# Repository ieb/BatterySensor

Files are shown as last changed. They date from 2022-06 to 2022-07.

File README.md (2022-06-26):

# Battery Sensor

Aim is to create a low power smat shunt batter sensor reporting volage, current and temperatire over ModbusRTU.

Shunt is measured using a MAX9918 shut amplifier amplifying 48x a 75mV/100A shunt scaled down to 50mV to keep the MAX9918 input optimal.
Temperature by a 10K NTC read by ADC using an interpolation table.
Voltage by direct ADC with a voltage divder
RS485 by MAX485

# Protocol

Modbus RTU - bigendian

# Holding registers - function 3 to read, 6 to set

Stored in EEPROM, which is typically reset on a firmware upgrade.

| Offset | Name | type  | details |
|---|---|---|---|
| 0 | Device Adddress | int16 | 1-254 modbus address, default is 2 |
| 1 | Voltage offset adjustment | int16 | Offset in 0.1mv steps eg 10 = 1mV |
| 2 | Voltage scale adjustment | int16 | scale in 1/10000th eg 10000 = 1x |
| 3 | Current offset adjustment | int16 | offset in 0.1mA steps eg 10 = 1mA |
| 4 | Current scale adjustment | int16 | scale in 1/10000th eg 10000 = 1x |
| 5 | Temperature offset adjustment | int16 | offset in C in 1/1000th eg 1000 = +1C |
| 6 | Temperature scale adjustment  | int16 | scale in C in 1/1000th eg 1000 = 1x |
| 7 | Serial Number | int16 | Device serial number, once set cannot be changed |

# Input Registers - function 4 to read

| Offset | Name | type | details |
|---|---|---|---|
| 0 | Voltage | int16  | Units 0.01V |
| 1 | Current | int16  | Units 0.01A |
| 2 | Temperature | int16  | 1 = 0.01C |
| 1001 | Recieved | uint16 | count of frames recieved |
| 1002 | Sent | uint16 | count off frames send |
| 1003 | Errors Recieved | uint16 | count off frames recieved with errors |
| 1004 | Ignored | uint16 | count off frames dropped |
| 1005 | Errors Sent | uint16 | count off error frames send |

# Other functions
* 17 - report - 4 bytes, uint8 device type (0x01), uint device on (0xff), int16 serial number (0xXXXX)

Exceptions are reported as per ModbuRTU Spec.

# MCU

Platform ATTiny8224
Could have also used a ATTiny84, but this has no uarts and requires ICSP programming.
Programmming using jtag2udpi on an Arduino Uno with avrdude.conf setup for the ATTiny8224, running at 5V.

# Voltage

The ATTiny ADC in 16bit using 4096 refrence through aa 32K/10K divider, gives withing 10mv of a 4 digit multi meter after calibration setting (0.9954 register 2 set to 9954). Hard to tell which is more accutage, probably the ADC. Voltage is stable with the LSB changing +- 1 or 2.

# Current

Multiple frustrating attempts with a current amplifier, eventually abandoned.

The originam MAX9918 had an unstable 75mV offset from the reference resistors at 0A which would not go, chip might have been damaged during soldering or the EP ground plane was not good enough.

2x INA169 that I had from years ago could not be made to amplify the input correctly at the required 47x gain. Looking back I had tried INA169 before and had problems eventually abandoning.

Now trying the Attiny3224 ADC + PGA at 16x which measures down to 0.0019mV perbit below 64mV differntial on the 16bit range with a 1024mV refrence, however this might really be 0.015625mV resolution as the 16 bit is oversampling 12bit. If it is, this represents a resolution of +-20mA which is perfectly reasonable for a 100A/75mV shunt. Quick testing indicates this is stable and repeatable with 10R on the input lines for protection from misconnection and 100nF accross the ADC inputs to remove high frequency components.

If that fails I will use one of the Alegro Hall chips, althought I prefer the simplicity of a shunt.

# debugging

Performed over serial on the second uart at 115200 baud.
Modbus is at 9600 baud 8N1

Building with DEVMODE (see main.cpp) defined allows the rs485 serial to be diverted to Serial1 and test patterns to be pasted from testpatterns.txt over the monitoring serial line.

Testing can be done with 

            pio run -e native 

which produces a native binary then

            cat testpattern.txt |  ./.pio/build/native/program

Which checks exercises the RS485 protocol using test patterns checking the response.

# Programming

Currently using jtag2udpi, via an Uno, but setting fuses seems hard
Needs a modified avrdude.conf file to add support for the attiny3224
pio run -t fuse -e attiny3224 does appear to work.

Fuses must be set to ensure the chip clock speed matches the compiled code. This only needs to be done once per chip.
It its not done the serial output doesnt sync with the baud rate and garbage is seen on the serial line.

    pio run -t fuses -e attiny3224

Looking at megaTinyCore support in the Arduino IDE using SerialUDPI is much better and more advanced.

    pio run -t upload -e attiny3224 

works ok for the moment.

# Board

For full details see the pcb/*
In outline.

            ------------------------------------------
            | a           1 2 3 4 5                 A|
            | b   MAX                      MAX      B|     
            | c   RS485   Atting3224       9918     C|     
            | d                                     D|     
            |     AMS1117                           E|
            ------------------------------------------     

            a = GND
            b = Vin (12v)
            c = RS485 A
            d = RS485 B

            1 = GND
            2 = +5V
            3 = UDPI
            4 = Debug RX
            5 = Debug TX

            A = Battery +Ve
            B = Shunt -
            C = Shunt +
            D = GND
            E = NTC

# Test client

in testclient/ requires python3.
install with 

    pip install -r requirements.txt

run with 

    python3 batterymon.py

# TODO

* [x] Check MAX9918 amplifier - Abandoned using MAX9918 as it had 75mV offset from its reference point and a lot of instability. Have switched to a pair of INA196 current amplifiers which so far draw much less current and seem stable
* [x] Test temperature
* [x] Test voltage
* [x] Test current - switched to direct to ADC which gives good 0mA stability, need to verify linearit
* [x] Test RS485 
* [x] Write Python Modbus RTU Controller to test for real.
* [ ] Calibrate
* [ ] Integrate with CanDiagnose controler to act as ModBus Controller for 1..n battery sensors.

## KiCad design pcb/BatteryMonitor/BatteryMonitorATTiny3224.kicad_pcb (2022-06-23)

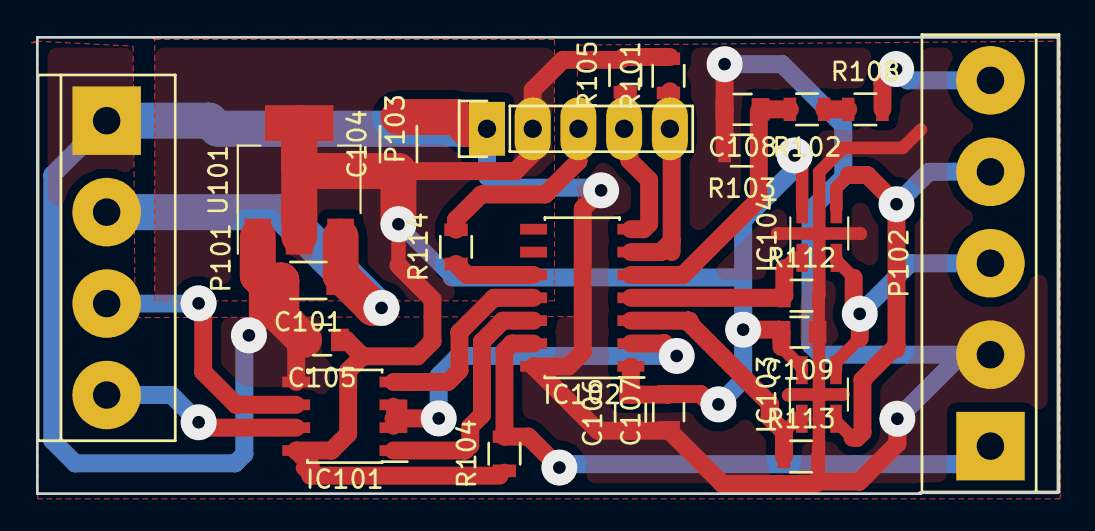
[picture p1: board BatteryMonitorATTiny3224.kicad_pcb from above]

Board: 2 copper layers, 56.7 x 25.4 mm, 24 parts (0 on the bottom side), 20 nets.

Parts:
C101, C104: 10uF; C_1206
C105, C106, C109: 100nF; C_0805
C107: 1nF; C_0805
C108: C; C_0805
IC101: MAX3485E; SOIC-8_3.9x4.9mm_Pitch1.27mm
IC102: ATTINY3224-SS; SOIC-14_3.9x8.7mm_Pitch1.27mm
IC103, IC104: INA169; SOT-23-5_HandSoldering
P101: RS485; bornier4
P102: Bat; bornier5
P103: Prog; Pin_Header_Straight_1x05
R101, R103, R104, R105, R108: 10K; R_0805
R102: 22K; R_0805
R112, R113: 47K; R_0805
R114: 270R; R_0805
U101: AMS1117; SOT-223-3Lead_TabPin2

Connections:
5v: C104.1, C105.1, C106.2, C107.2, C109.2, IC101.8, IC102.1, IC103.5, IC104.5, P103.2, R101.2, R104.1, R105.2, U101.2
BatSenseV: C108.1, IC102.5, R102.2, R103.1
BatV+: P102.5, R108.2
CurSenseV: IC102.4, IC104.1, R112.1
GND: C101.2, C104.2, C105.2, C106.1, C107.1, C108.2, C109.1, IC101.5, IC102.14, IC103.2, IC104.2, P101.1, P102.2, P103.1, R103.2, R112.2, R113.2, U101.1
NTC: IC102.13, P102.1, R104.2
unnamed: IC102.10, R114.1
unnamed: R102.1, R108.1
RS485-A: IC101.6, P101.3
RS485-B: IC101.7, P101.4
RS+: IC103.4, IC104.3, P102.3
RS-: IC103.3, IC104.4, P102.4
RX: IC101.1, IC102.12
RXDebug: IC102.6, P103.5, R101.1
Sense-: IC102.3, IC103.1, R113.1
TX: IC101.4, IC102.11
TXDebug: IC102.7, P103.4, R105.1
TXEN: IC101.2, IC101.3, IC102.2
UDPI: P103.3, R114.2
Vin: C101.1, P101.2, U101.3

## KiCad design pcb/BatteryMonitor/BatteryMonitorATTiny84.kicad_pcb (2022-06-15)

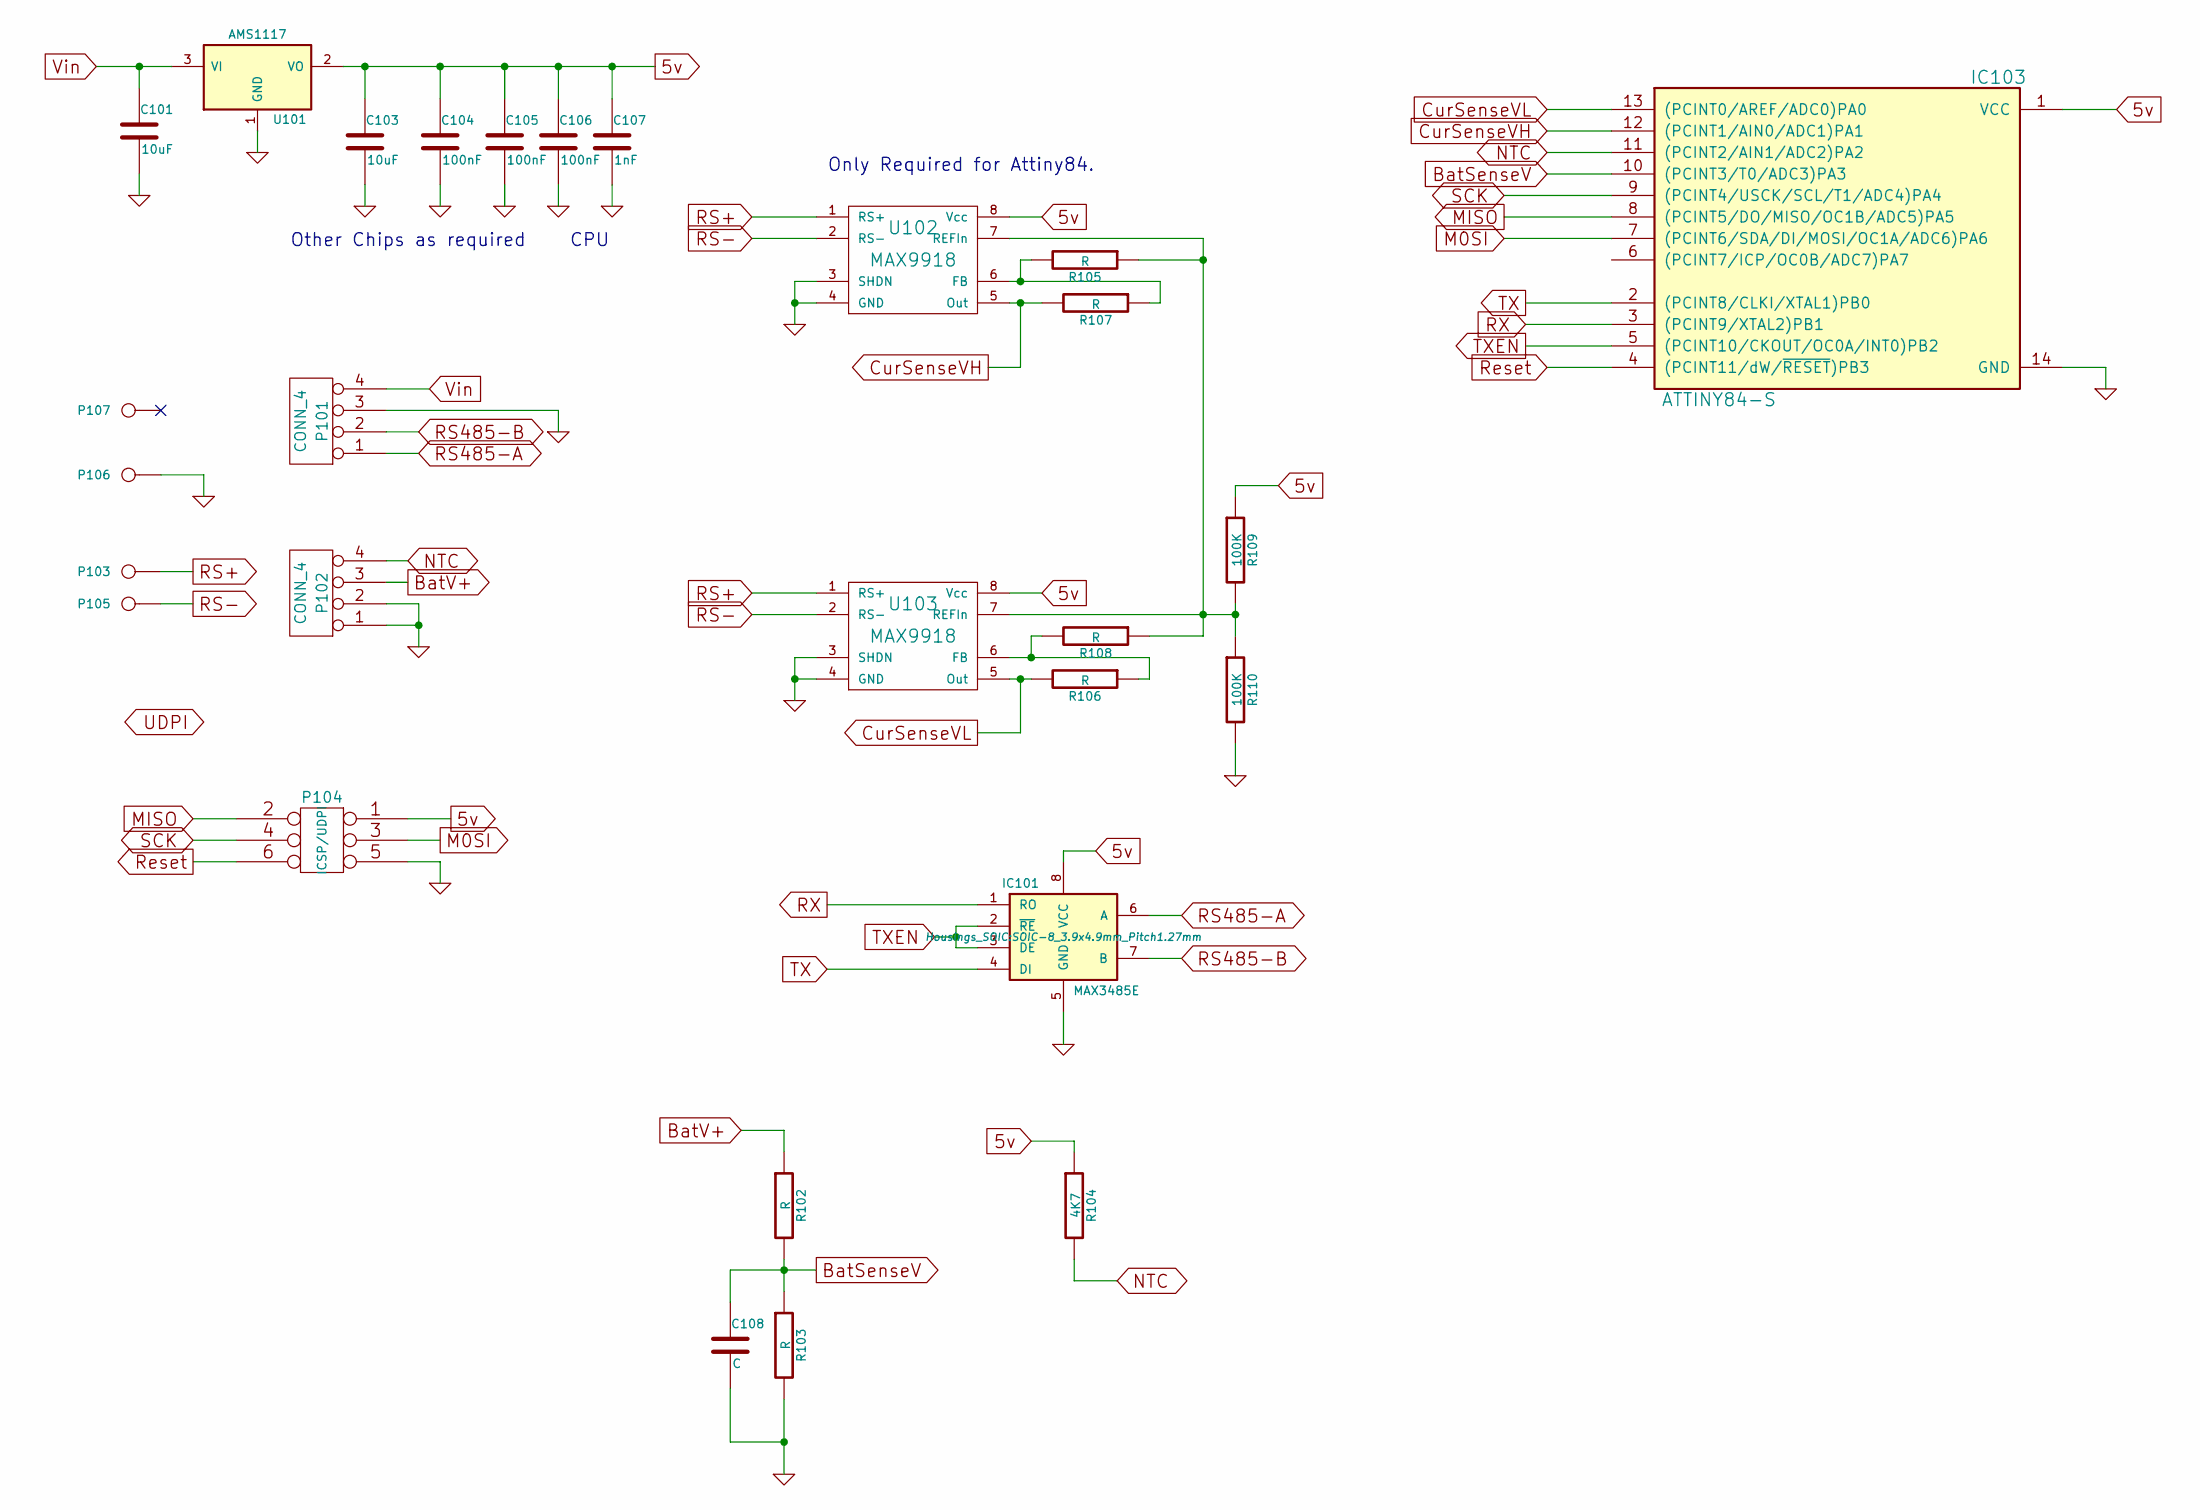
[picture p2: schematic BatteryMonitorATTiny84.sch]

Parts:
C101, C103: 10uF; C_1206
C104, C105, C106: 100nF; C_0805
C107: 1nF; C_0805
C108: C; C_0805
IC101: MAX3485E; SOIC-8_3.9x4.9mm_Pitch1.27mm
IC103: ATTINY84-S; DIP-14_W7.62mm
P101, P102: CONN_4; bornier4
P103, P106, P107: RS+; 1pin
P104: ICSP/UDPI; Pin_Header_Straight_2x03
P105: RS-; 1pin
R102, R103, R105, R106, R107, R108: R; R_0805
R104: 4K7; R_0805
R109, R110: 100K; R_0805
U101: AMS1117; SOT-223-3Lead_TabPin2
U102, U103: MAX9918; SOIC-8_3.9x4.9mm_Pitch1.27mm

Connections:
5v: C103.1, C104.1, C105.1, C106.1, C107.1, IC101.8 (VCC), IC103.1 (VCC), P104.1, R104.1, R109.1, U101.2 (VO), U102.8 (Vcc), U103.8 (Vcc)
BatSenseV: C108.1, IC103.10 ((PCINT3/T0/ADC3)PA3), R102.2, R103.1
BatV+: P102.3, R102.1
CurSenseVH: IC103.12 ((PCINT1/AIN0/ADC1)PA1), R107.2, U102.5 (Out)
CurSenseVL: IC103.13 ((PCINT0/AREF/ADC0)PA0), R106.2, U103.5 (Out)
GND: C101.2, C103.2, C104.2, C105.2, C106.2, C107.2, C108.2, IC101.5 (GND), IC103.14 (GND), P101.3, P102.1, P102.2, P104.5, P106.1, R103.2, R110.2, U101.1 (GND), U102.3 (SHDN), U102.4 (GND), U103.3 (SHDN), U103.4 (GND)
M0SI: IC103.7 ((PCINT6/SDA/DI/MOSI/OC1A/ADC6)PA6), P104.3
MISO: IC103.8 ((PCINT5/DO/MISO/OC1B/ADC5)PA5), P104.2
NTC: IC103.11 ((PCINT2/AIN1/ADC2)PA2), P102.4, R104.2
unnamed: R105.1, R108.1, R109.2, R110.1, U102.7 (REFIn), U103.7 (REFIn)
unnamed: R105.2, R107.1, U102.6 (FB)
unnamed: R106.1, R108.2, U103.6 (FB)
RS485-A: IC101.6 (A), P101.1
RS485-B: IC101.7 (B), P101.2
RS+: P103.1, U102.1 (RS+), U103.1 (RS+)
RS-: P105.1, U102.2 (RS-), U103.2 (RS-)
RX: IC101.1 (RO), IC103.3 ((PCINT9/XTAL2)PB1)
Reset: IC103.4 ((PCINT11/dW/~RESET~)PB3), P104.6
SCK: IC103.9 ((PCINT4/USCK/SCL/T1/ADC4)PA4), P104.4
TX: IC101.4 (DI), IC103.2 ((PCINT8/CLKI/XTAL1)PB0)
TXEN: IC101.2 (~RE~), IC101.3 (DE), IC103.5 ((PCINT10/CKOUT/OC0A/INT0)PB2)
Vin: C101.1, P101.4, U101.3 (VI)

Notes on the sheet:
Only Required for Attiny84.
CPU
Other Chips as required

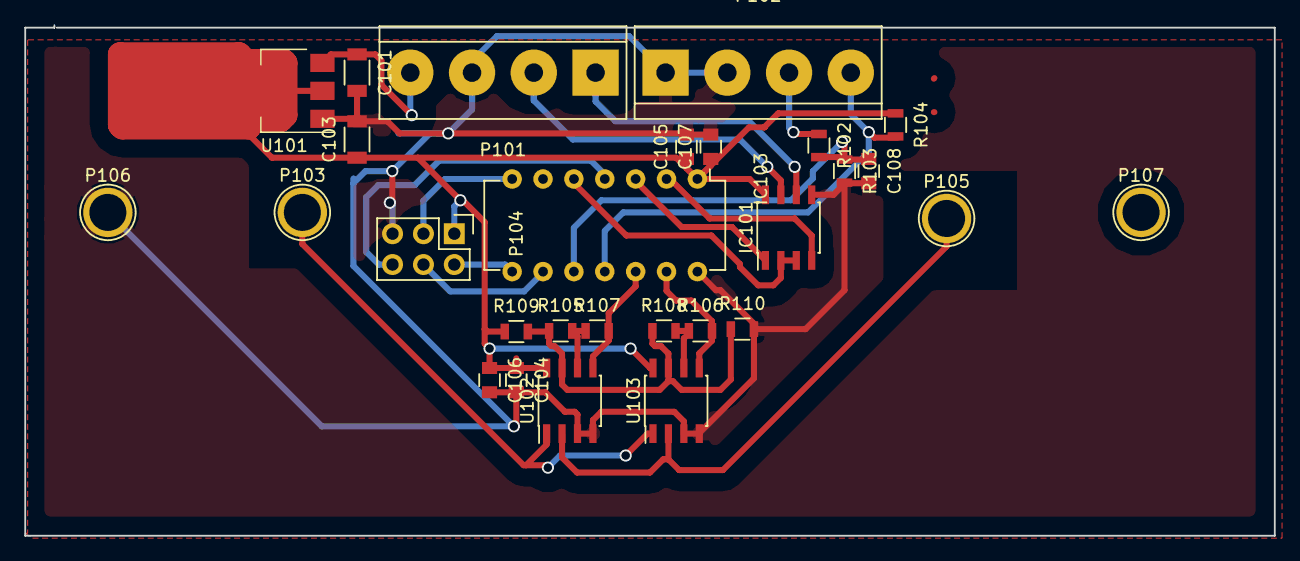
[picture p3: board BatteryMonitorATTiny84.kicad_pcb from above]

Board: 2 copper layers, 102.8 x 42.0 mm, 28 parts (0 on the bottom side), 22 nets.

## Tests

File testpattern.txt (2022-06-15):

# contains a test patter of modbus.
# Modbus ASCII Decimal format
# starts with a $ for decimal
# numbers > 255 are read as 2 a bigendian 16bit register.
# <= 255 are read as a byte, and must be preceeded by 00 to fill a register.
# lines that start with a # are ignored, everything else is read.
# This is not the Modbus ASCII format which is purely hex.
# Modbus ASCII standard Hex format
# lines start with a : followed by each byte encode in hex chars (no preceeding 0x) ending with a new line.
# No CRC Checksums are added, these are calculated at the end of each line.

# read 6 holding registers
:020300000006
:>02030C000200000064000000640000
# read 6 input registers
:020400000006
:>02040C00500000FFD0000000000000
# read slave ID, functoin 17, 0x11
# Should respond with 0x01 0xff 0x00 0x00
:0211
:>02110401FF0000
#
# Unexptected Exception response
# should respond with exception code 1
:02080000000604050601
:>028801
# update device address to 4
# should echo back the update
:020600000004
:>020600000004
# Read holding registers from device now at4
# should respond with registers.
:040300000006
:>04030C000400000064000000640000
# update serial number to 3256
$ 4 6 0 7 3256
$> 4 6 0 7 3256
# update serial number to 3010 should be denied
# should responmd with exception code 3
$ 4 6 0 7 3010
:>048603
# update voltage offset to -123
$ 4 6 0 1 -1238
$> 4 6 0 1 -1238
# update voltage scale to 234
$ 4 6 0 2 0 234
$> 4 6 0 2 0 234
# update current offset to 128
$ 4 6 0 3 0 128
$> 4 6 0 3 0 128
# update current scale to 834
$ 4 6 0 4 834
$> 4 6 0 4 834
# update temperature offset to 128
$ 4 6 0 5 0 128
$> 4 6 0 5 0 128
# update temperature scale to 844
$ 4 6 0 6 844
$> 4 6 0 6 844
# Read holding registers from 4
:040300000006
:>04030C0004FB2A00EA008003420080
exit

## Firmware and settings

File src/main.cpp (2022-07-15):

#ifdef NATIVE
#include "nativemocks.h"
#include "holdingregisters.h"

SerialClass * rs485 = &Serial;
SerialClass * debug = &Serial1;


#else
#include <Arduino.h>
#include <avr/eeprom.h>



// #define DEVMODE 1
#ifdef DEVMODE
#include "devmoders485.h"
DevRS485Class * rs485 = &DevRS485;
UartClass * debug = &Serial;
#else
UartClass * rs485 = &Serial1;
UartClass * debug = &Serial;
#endif

#include "modbus.h"
#include "holdingregisters.h"
#include "commandline.h"
#endif

#include "stackcheck.h"

Modbus modbus = Modbus(rs485, debug);
CommandLine commandLine = CommandLine(debug, &modbus);
/*
RAM:   [===       ]  29.5% (used 151 bytes from 512 bytes)
Flash: [===       ]  27.2% (used 2226 bytes from 8192 bytes)

After adding in the EEPROM and holding revisters
RAM:   [===       ]  33.8% (used 173 bytes from 512 bytes)
Flash: [===       ]  34.4% (used 2818 bytes from 8192 bytes)

Added reading for voltages and temp
RAM:   [===       ]  33.8% (used 173 bytes from 512 bytes)
Flash: [=====     ]  54.8% (used 4488 bytes from 8192 bytes)

Added write and save holding registers. 337 bytes free RAM
RAM:   [===       ]  34.2% (used 175 bytes from 512 bytes)
Flash: [======    ]  59.5% (used 4874 bytes from 8192 bytes)

Dropped EEPROM class and moved registers into eeprom storage.
Moved CRC code into main and removed uneeded code.
Added stack checker
Refactored register output to be more efficient.
RAM:   [===       ]  31.2% (used 160 bytes from 512 bytes)
Flash: [====      ]  44.5% (used 3646 bytes from 8192 bytes)

// Moved to Attiny3224 which has more FLASH and RAM and far better ADC's

Advanced Memory Usage is available via "PlatformIO Home > Project Inspect"
RAM:   [=         ]  11.7% (used 360 bytes from 3072 bytes)
Flash: [====      ]  43.5% (used 14245 bytes from 32768 bytes)
Building .pio/build/attiny3224/firmware.hex

Clock speed = 16000000L
Oscillator = internal
BOD level = 2.6v
Save EEPROM = yes
UPDI pin mode = updi
-------------------------
Using manually specified: /dev/cu.wchusbserial26220

Selected fuses:
-------------------------
[fuse0 / wdtcfg   = 0x00]
[fuse1 / bodcfg   = 0x54]
[fuse2 / osccfg   = 0x01]
[fuse4 / tcd0cfg  = 0x00]
[fuse5 / syscfg0  = 0xC5]
[fuse6 / syscfg1  = 0x06]
[fuse7 / append   = 0x00]
[fuse8 / bootend  = 0x00]
[lock  / lockbit  = 0xC5]
-------------------------

*/
/* definition to expand macro then apply to pragma message */
#define VALUE_TO_STRING(x) #x
#define VALUE(x) VALUE_TO_STRING(x)
#define VAR_NAME_VALUE(var) #var "="  VALUE(var)

#pragma message(VAR_NAME_VALUE(CLOCK_TUNE_INTERNAL))
#pragma message(VAR_NAME_VALUE(F_CPU))

#define DEVICE_TYPE 0x01
#define DEVICE_ON 0xff



bool diagnosticsEnabled = false;



void setDiagnostics(bool enabled) {
  diagnosticsEnabled = enabled;
  modbus.setDiagnostics(enabled);
}


void loadDefaults() {
  // defaults need to be reset, numbers are little endian, so they can be read directly.
  // when sending out bytes need to be swapped.
  uint8_t eepromContents[HR_SIZE];
  eeprom_read_block((void*)&eepromContents[0], (const void*)0, HR_SIZE);
  uint16_t crcv =  modbus.crc16(&eepromContents[0], HR_SIZE-2);
  uint16_t crcvs = (0xff&eepromContents[HR_CRC]) | (0xff00&(eepromContents[HR_CRC+1]<<8)); // little endian
  if (crcv != crcvs ||eepromContents[HR_DEVICE_ADDRESS] == 0 ) {
    debug->print(F("EPROM not initialised"));
    for(uint8_t i = 0; i < HR_SIZE-2; i++) {
      eepromContents[i] = pgm_read_byte_near(epromDefaultValues+i);
    }
    crcv =  modbus.crc16(&eepromContents[0], HR_SIZE-2);
    eepromContents[HR_CRC] = 0xff&(crcv);
    eepromContents[HR_CRC+1] = 0xff&(crcv>>8); // little endian
    eeprom_update_block(&eepromContents[0], (void*)0, HR_SIZE);
  } else {
    debug->print(F("EPROM initialised "));
    debug->print(crcv);
    debug->print(F(" = "));
    debug->print(crcvs);
    debug->print(F("  device "));
    debug->println(eepromContents[HR_DEVICE_ADDRESS]);
  }
  modbus.setDeviceAddress(eepromContents[HR_DEVICE_ADDRESS]);
}

/* definition to expand macro then apply to pragma message */
#define VALUE_TO_STRING(x) #x
#define VALUE(x) VALUE_TO_STRING(x)
#define VAR_NAME_VALUE(var) #var "="  VALUE(var)

//#pragma message(VAR_NAME_VALUE(PIN_HWSERIAL0_TX))


void setup() {
  modbus.begin();
  debug->begin(9600, SERIAL_8N1);
  pinMode(PIN_PA3, INPUT); // NTC
  pinMode(PIN_PA5, INPUT); //Sense -
  pinMode(PIN_PA6, INPUT); // Sense +
  pinMode(PIN_PA7, INPUT); // Bat

  debug->println(F("Starting Battery Monitor"));
  loadDefaults();
}







int16_t readVoltage(bool logEnabled = false ) {
  uint16_t dw = eeprom_read_word((const uint16_t *)HR_VOLTAGE_SCALE);
  int16_t voltageScale = (int16_t)(0xffff&dw);
  dw = eeprom_read_word((const uint16_t *)HR_VOLTAGE_OFFSET);
  int16_t voltageOffset = (int16_t)(0xffff&dw);

  // Divider == 10/42  (R1 = 32, R2 = 10)
  // 16 bit 4.096, mV/bit == 4.096/2^16 == 0.0625 mVadc/bit
  // (4.096/2^16)*42/10 = 0.2625 mVin/bit

  // calibration
  // v
#define MV_PER_16BIT_ADC 0.0625
#define MV_PER_16BIT_VIN 0.2625
  analogReference(INTERNAL4V096); 
  delayMicroseconds(100); // wait at least 60us for the reference change to act
  analogSampleDuration(300);
  int32_t reading = analogReadEnh(PIN_PA7, 16); // discard
  analogSampleDuration(300);
  reading = analogReadEnh(PIN_PA7, 16);
  float mvAdc = reading*MV_PER_16BIT_ADC;
  float mvVin = reading*MV_PER_16BIT_VIN*(0.0001*voltageScale)+(0.1*voltageOffset);

  if ( logEnabled ) {
    debug->print("Read Voltage offset=");
    debug->print(voltageOffset);
    debug->print(" scale=");
    debug->print(voltageScale);
    debug->print(" adc=");
    debug->print(reading);
    debug->print(" mVadc=");
    debug->print(mvAdc);
    debug->print(" mVin=");
    debug->println(mvVin);
  }

  return (int16_t) (mvVin/10);  
}




/**
 * @brief read current as an int 1 == 10mA
 * 
 * @return int16_t 
 */
int16_t readCurrent(bool logEnabled = false) {
  uint16_t dw = eeprom_read_word((const uint16_t *)HR_CURRENT_SCALE);
  int16_t currentScale = (int16_t)(0xffff&dw);
  dw = eeprom_read_word((const uint16_t *)HR_CURRENT_OFFSET);
  int16_t currentOffset = (int16_t)(0xffff&dw);




#define SHUNT75_INTERNAL4V096_MA_16BIT_LSB 3.546099291
#define SHUNT75_INTERNAL2V048_MA_16BIT_LSB 1.773049645
#define SHUNT75_INTERNAL1V024_MA_16BIT_LSB 0.8865248227

#define INTERNAL4V096_MV_16BIT_LSB  0.125 // 4096/2^15  
#define INTERNAL2V048_MV_16BIT_LSB  0.0625 // 2048/2^15
#define INTERNAL1V024_MV_16BIT_LSB  0.03125 // 1024/2^15
#define INTERNAL1V024X2_MV_16BIT_LSB 0.015625
#define INTERNAL1V024X4_MV_16BIT_LSB 0.0078125
#define INTERNAL1V024X8_MV_16BIT_LSB 0.00390625
#define INTERNAL1V024X16_MV_16BIT_LSB 0.001953125
#define MAFACTOR 1333.3333333 //100000/75 in mA

  // set sample time to get a quick estimate of which range to use.
  analogSampleDuration(30);
  analogReference(INTERNAL4V096);  
  delayMicroseconds(100); // wait at least 60us for the reference change to act
  // determine the range 2048/2^^15  0.0625 mV per bit
  // 200mV is over range
  // 
  uint8_t gain = 0;
  float scale = INTERNAL4V096_MV_16BIT_LSB;
  int32_t sample = analogReadDiff(PIN_PA6,PIN_PA5, 16,0); // dispose
  sample = analogReadDiff(PIN_PA6,PIN_PA5, 16,0);
  if ( sample < 1000 && sample > -1000 ) {
    // less than +- 62.5mV 1024 16x range
    gain = 16;
    scale = INTERNAL1V024X16_MV_16BIT_LSB;
    analogReference(INTERNAL1V024);
  } else if ( sample < 2000 && sample > -2000 ) {
    // less than +- 125mV 1024 8x range 
    gain = 8;
    scale = INTERNAL1V024X8_MV_16BIT_LSB;
    analogReference(INTERNAL1V024);  
  } else if ( sample < 4000 && sample > -4000 ) {
    // less than  +-250mV 1024 4x range 
    gain = 4;
    scale = INTERNAL1V024X4_MV_16BIT_LSB;
    analogReference(INTERNAL1V024);  
  } else if ( sample < 16000 && sample > -16000 ){
    // greater than 250mV and less than 1v can be read on the 4096 range at 16bit
    scale = INTERNAL4V096_MV_16BIT_LSB;
    gain = 0;
  } else {
    // something wrong, > 1V, return 0
    return 0;
  }
  analogSampleDuration(300);
  delayMicroseconds(100); // wait at least 60us for the reference change to act

  int32_t reading = analogReadDiff(PIN_PA6,PIN_PA5, 16, gain); // discard
  reading = analogReadDiff(PIN_PA6,PIN_PA5, 16, gain);
  float mV = scale*reading;

  float current = mV*MAFACTOR;
  current *= (0.0001*currentScale);
  current += (0.1*currentOffset);
  if ( logEnabled ) {
    debug->print("Read Current gain=");
    debug->print(gain);
    debug->print(" offset=");
    debug->print(currentOffset);
    debug->print(" scale=");
    debug->print(currentScale);
    debug->print(" mV="); 
    debug->print(mV); 
    debug->print(" mA="); 
    debug->print(current);
    debug->print(" output="); 
    debug->println((int16_t)current/10);
  }

  return (int16_t)current/10; // need output to be in units of 0.01A
}







/**
 * @brief ADC readings at temperatures from MIN_NTC_TEMPERATURE to MAX_NTC_TEMPERATURE in sptes of NTC_TABLE_STEP
 * calculated using https://www.skyeinstruments.com/wp-content/uploads/Steinhart-Hart-Eqn-for-10k-Thermistors.pdf
 * https://www.gotronic.fr/pj2-mf52type-1554.pdf MC53-10K B 3950K
 * 	Supply 	5		
	Rtop	10		
C	R in K	V	ADC
-10	56.06	4.2431123221	4243.1123221314
0	32.96	3.8361266294	3836.1266294227
10	20	3.3333333333	3333.3333333333
20	12.51	2.7787649933	2778.7649933363
30	8.048	2.2296099291	2229.609929078
40	5.312	1.7345872518	1734.5872518286
50	3.588	1.3202826023	1320.2826022962
60	2.476	0.992305226	992.305226034
70	1.743	0.7421442562	742.1442561526
80	1.25	0.5555555556	555.5555555556
90	0.911	0.4174686097	417.46860966
100	0.6744	0.3158959754	315.8959754178
110	0.5066	0.2410865551	241.0865551177

 */
const int16_t ntcTable[] PROGMEM= {
4243,
3836,
3333,
2779,
2230,
1735,
1320,
992,
742,
556,
417,
316,
241
  };
#define NTC_TABLE_LENGTH 13
#define MIN_NTC_TEMPERATURE -10.0
#define MAX_NTC_TEMPERATURE 110.0
#define NTC_TABLE_STEP 10.0


int16_t readTemperature(bool logEnabled = false ) {
  uint16_t dw = eeprom_read_word((const uint16_t *)HR_TEMPERATURE_SCALE);
  int16_t temperatureScale = (int16_t)(0xffff&dw);
  dw = eeprom_read_word((const uint16_t *)HR_TEMPERATURE_OFFSET);
  int16_t temperatureOffset = (int16_t)(0xffff&dw);

  
  

  // scale for supply voltage, which should be 5V
  // 5v / 10 = 0.5v,  at 0.00025v/LSB = 5V would be 2000
  // unforotunately must do this as float 
  analogReference(INTERNAL4V096); // 1mV per LSB
  delayMicroseconds(100); // wait at least 60us for the reference change to act
  analogSampleDuration(300);
  int16_t reading = analogReadEnh(PIN_PA3, 12, 1);

  float temp = MAX_NTC_TEMPERATURE;
  int16_t cvp = ((int16_t)pgm_read_dword(&ntcTable[0]));
  if ( reading > cvp ) {
    temp = MIN_NTC_TEMPERATURE;
  } else {
    for (int i = 1; i < NTC_TABLE_LENGTH; i++) {
      int16_t cv = ((int16_t)pgm_read_dword(&ntcTable[i]));
      if ( reading > cv ) {
        temp = ((cvp-reading)*NTC_TABLE_STEP);
        temp /= (cvp-cv);
        temp += ((i-1)*NTC_TABLE_STEP)+MIN_NTC_TEMPERATURE;
        break;
      }
      cvp = cv;
    }
  }
  // perhaps this could be integer arithmetic ?
  float outputTemp = temp+(0.001*temperatureOffset);
  outputTemp *= (0.001*temperatureScale);
  outputTemp /= 0.01;
  if ( logEnabled ) {
    debug->print("Read Temperature offset=");
    debug->print(temperatureOffset);
    debug->print(" scale=");
    debug->print(temperatureScale);
    debug->print(" adc=");
    debug->print(reading);
    debug->print(" temp=");
    debug->print(temp);
    debug->print(" output=");
    debug->println(outputTemp);
  }
  return (int16_t) (outputTemp);
}



/**
 * @brief function 4 sent input registers
 * 
 */
int8_t readInput() {
  int16_t reg = modbus.getRegisterStart(); 
  int16_t count = modbus.getRegisterCount(); 
  if ( count > MAX_REGISTER_COUNT ) {
    modbus.sendFunctionCodeError(EXCEPTION_ILEGAL_DATA_VALUE);
  } else if ( reg > modbus.getMaxInputRegister() ) {
    modbus.sendFunctionCodeError(EXCEPTION_ILEGAL_DATA_ADDRESS);
  } else {
    modbus.startOutputFrame();
    for(int r = 0; r < count; r++) {
      switch (r+reg) {
        case 0: // voltage  0.01V  (+320v to -320v)
          modbus.addOutputInt(readVoltage(diagnosticsEnabled));
          break;
        case 1: // current 0.01A  (+320A to -320A)
          modbus.addOutputInt(readCurrent(diagnosticsEnabled));
          break;
        case 2: // temperature 0.01C (+320C to -273C)
          modbus.addOutputInt(readTemperature(diagnosticsEnabled));
          break;
        default:
          modbus.outputRegister((r+reg));
      }
    }
    modbus.send();
  }
}


/**
* @brief function 3, send holding registers.
* 
*/
int8_t readHolding() {
    int16_t reg = modbus.getRegisterStart(); 
    int16_t count = modbus.getRegisterCount(); 
    if ( count > MAX_HOLDING_REGISTER ) {
        modbus.sendFunctionCodeError(EXCEPTION_ILEGAL_DATA_VALUE);
    } else if ( (reg+count-1)*2 >= HR_SIZE ) {
        modbus.sendFunctionCodeError(EXCEPTION_ILEGAL_DATA_ADDRESS);
    } else {
      modbus.startOutputFrame();
      for(int r = 0; r < count; r++) {     
          if ( (reg+r)*2 >= HR_CRC ) {
            modbus.addOutputInt(0x0000);
          } else {
            // covert the dword to an int16_t before sending by masking it with 0xffff
            uint16_t epromVal = eeprom_read_word((const uint16_t *)((reg+r)*2));
            int16_t regVal = (int16_t)(0xffff&epromVal);
            modbus.addOutputInt(regVal);

          }
      }
      modbus.send();
    }
};


/**
 * @brief update 1 hoding register.
 * 
 */
void writeHolding() {
  int16_t regPos = modbus.getRegisterStart()*2; 
  if ( regPos < 0 || regPos >= HR_CRC ) {
    modbus.sendFunctionCodeError(EXCEPTION_ILEGAL_DATA_ADDRESS);
  } else {
    int16_t value = modbus.getRegisterValue();
    uint8_t epromContents[HR_SIZE];
    eeprom_read_block((void*)&epromContents[0], (const void*)0, HR_SIZE);
    int16_t currentValue = epromContents[regPos] | (0xff00&(epromContents[regPos+1]<<8));
    if (regPos == HR_SERIAL_NUMBER && currentValue != 0) {
      modbus.sendFunctionCodeError(EXCEPTION_ILEGAL_DATA_VALUE);
    } else if ( currentValue != value) {
      // store little endian
      epromContents[regPos] = 0xff&value;
      epromContents[regPos+1] = 0xff&(value>>8);
      uint16_t crcv =  modbus.crc16(&epromContents[0], HR_SIZE-2);
      epromContents[HR_CRC] = 0xff&(crcv);
      epromContents[HR_CRC+1] = 0xff&(crcv>>8); // little endian
      eeprom_update_block((const void*)&epromContents[0], (void*)0, HR_SIZE);
      // update device address, which may have changed.
      modbus.setDeviceAddress(epromContents[HR_DEVICE_ADDRESS]);
      modbus.setToSend(6);
      modbus.send();
    }
  }
}

void writeSlaveId() {
  modbus.startOutputFrame();
  modbus.addOutputByte(DEVICE_TYPE);
  modbus.addOutputByte(DEVICE_ON);
  modbus.addOutputInt(eeprom_read_word((const uint16_t*) HR_SERIAL_NUMBER));
  modbus.send();
}


void loop() {
  commandLine.checkCommand();
  int8_t functionCode = modbus.readQuery();
  unsigned long start = micros();
  switch (functionCode) {
    case 0:
     // noop
      break;
    case 3: // read holding
      readHolding();
      if ( diagnosticsEnabled ) {
        debug->print(F("read holding time="));
        debug->print(micros()-start);
        debug->println(F("us"));
      }
      break;
    case 4: // read input
      readInput();
      if ( diagnosticsEnabled ) {
        debug->print(F("read input time="));
        debug->print(micros()-start);
        debug->println(F("us"));
      }
      break;
    case 6: // write single holding
      writeHolding();
      if ( diagnosticsEnabled ) {
        debug->print(F("write holding time="));
        debug->print(micros()-start);
        debug->println(F("us"));
      }
      break;
    case 17: // report slave ID
      writeSlaveId();
      if ( diagnosticsEnabled ) {
        debug->print(F("report slave time="));
        debug->print(micros()-start);
        debug->println(F("us"));
      }
      break;
    default:
      if ( diagnosticsEnabled ) {
        debug->println(F("unexpected function"));
      }
      modbus.sendFunctionCodeError(EXCEPTION_ILEGAL_FUNCTION);
      // respond with error
  }



}

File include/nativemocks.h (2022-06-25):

#ifdef NATIVE
#include <stdlib.h>
#include <stdio.h>
#include <stdint.h>
#include <sys/time.h>
#include <iostream>
#include <iomanip>
#include <unistd.h>
#include <inttypes.h>

typedef unsigned char byte;


#define digitalWrite(pin,level)  std::cout << "Digital pin:" << pin << " level:" << level << std::endl

#define CRC16                   0x1021
#define HIGH 1
#define LOW 0
#define INPUT 1
#define OUTPUT 0
#define A5 5
#define A6 6
#define A7 7
#define PROGMEM 
#define F(x) x
#define SERIAL_RS485
#define SERIAL_8N1 0
#define INTERNAL4V096 1
#define INTERNAL2V048 2
#define INTERNAL1V024 3

#define PIN_A5  5
#define PIN_A6  6
#define PIN_A7  7
#define PIN_PA3 3
#define PIN_PA4 4
#define PIN_PA5 5
#define PIN_PA6 6
#define PIN_PA7 7
#define HEX 16


// CRC POLYNOME = x15 + 1 =  1000 0000 0000 0001 = 0x8001
uint16_t crc16(const uint8_t *array, uint16_t length, const uint16_t polynome,
               const uint16_t startmask, const uint16_t endmask, 
               const bool reverseIn, const bool reverseOut)
{
  uint16_t crc = startmask;
  while (length--) 
  {
    uint8_t data = *array++;
    crc ^= ((uint16_t)data) << 8;
    for (uint8_t i = 8; i; i--) 
    {
      if (crc & (1 << 15))
      {
        crc <<= 1;
        crc ^= polynome;
      }
      else
      {
        crc <<= 1;
      }
    }
  }
  crc ^= endmask;
  return crc;
}

void pinMode(int pin, int mode) {

}
void delay(int millis) {
    usleep(millis*1000);
}
void delayMicroseconds(int us) {
    usleep(us);
}


unsigned long micros(){
    static unsigned long start = 0;
    struct timeval tv;
    gettimeofday(&tv,NULL);
    unsigned long time_in_micros = 1000000 * tv.tv_sec + tv.tv_usec;
    if (start == 0) {
        start = time_in_micros;
        return 0;
    } 
    return time_in_micros-start;
}

int16_t analogRead(uint8_t pin) {
    return 2045;
}

int32_t analogReadEnh(uint8_t pin, uint8_t bits=12,  uint8_t gain=0) {
    int16_t max = 1<<bits;
    return max/2;
} 
int32_t analogReadDiff(uint8_t pinA, uint8_t pinB, uint8_t bits=12,  uint8_t gain=0) {
    return 100;
} 
void analogReference(int ref) {

}
void analogSampleDuration(int delay) {

}
int16_t pgm_read_dword(const int16_t *intp) {
    return *intp;
}

uint8_t  pgm_read_byte_near(const uint8_t *ptr) {
    return *ptr;
}

#define DEBUG(x) std::cout << "Debug:" << x << std::endl




class SerialClass {
    public:
        SerialClass() {};
        void begin(uint32_t baud, uint16_t options) { this->baud = baud; this->options = options;};
        int available() {
            if ( pos > 0 ) {
                // dont read more while the buffer has data in it.
                std::cout << "Buffer has " << pos << std::endl;
                return pos;
            }

            std::cout << ">";
            std::string line;
            std::getline( std::cin, line );
            char * cline = (char *) line.c_str();
            if ( line == "exit") {
                exit(0);
            }
            

            size_t start = pos;
            if ( cline[0] == ':') {
                std::cout << "Modbus Ascii " << line << std::endl;
                // ASCII Modbus
                char *clineptr = &cline[1];
                if ( *clineptr == '>') clineptr++;
                char bytebuf[5];
                bytebuf[0] = '0';
                bytebuf[1] = 'x';
                bytebuf[4] = '\0';
                                
                while(pos < 78 && *clineptr != '\0') {
                    bytebuf[2] = *(clineptr++);
                    if ( *clineptr != '\0') {
                        bytebuf[3] = *(clineptr++);
                    }
                    int x = strtol((const char*)bytebuf, nullptr, 16);
                    readbuffer[pos++] = 0xff&x;
                }
            } else if ( cline[0] == '$') {
                std::cout << "Modbus Decimal " << line << std::endl;
                // fill the buffer up with hex and return the buffer size
                char *clineptr = &cline[1];
                if ( *clineptr == '>') clineptr++;
                
                while(pos < 78 && *clineptr != '\0') {
                    int x = strtol((const char*)clineptr, &clineptr, 10);
                    while( isspace(*clineptr) && *clineptr != '\0') clineptr++;
                    if ( x > 255 || x < -255 ) {
                        readbuffer[pos++] = 0xff&(x>>8);
                        readbuffer[pos++] = 0xff&(x);
                    } else {
                        readbuffer[pos++] = 0xff&(x);
                    }
                }
            } else {
                std::cout << "Noop " << line << std::endl;
                return pos;
            }

            // append the CRC.
            uint16_t crcVal = crc16((const uint8_t *) &readbuffer[start], pos-start, CRC16, 0, 0, false, false);
            printf("CRC adding %ld  for %ld as %X \n",start, pos-start, crcVal);
            readbuffer[pos++] = 0xff&(crcVal>>8);
            readbuffer[pos++] = 0xff&crcVal;


            std::cout << "Buffer now " << pos << " long" << std::endl;
            char opbuffer[10];
            for (int i = 0; i < pos; i++) {
                printf("%02X ", readbuffer[i]);
            }
            std::cout << std::endl;

            if ( cline[1] == '>') {
                int fails = 0;
                for(int i = 0; i < pos; i++) {
                    if(readbuffer[i] != writebuffer[i]) {
                        printf("Check failed pos %d %X != %X \n", i, readbuffer[i], writebuffer[i]);
                        fails++;
                    }
                }
                if ( fails == 0) {
                    printf("Check Ok\n");
                } else {
                    exit(1);
                }
                pos = 0;
                return 0;
            } else {
                return pos;
            }
            
        };
        size_t readBytes(uint8_t *buffer, size_t len) {    
            size_t l = std::min(pos, len);
            for ( size_t i = 0; i < l; i++) {
                buffer[i] = readbuffer[i];
            }
            for ( size_t i = l; i < pos; i++) {
                readbuffer[i-pos] = readbuffer[pos];
            }
            pos -= l;
            return l;
        };
        void write(uint8_t *buffer, size_t len ) {
            std::cout << ">:";
            for (int i = 0; i < len; ++i) {
                writebuffer[i] = buffer[i];
                printf("%02X ", buffer[i]);
            }
            std::cout << std::endl;
        };
        void flush() {
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

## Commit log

2022-06-15 Initial Commit, code and pcb implemented
    [BatteryMonitorATTiny3224.kicad_pcb, BatteryMonitorATTiny3224.sch, BatteryMonitorATTiny84.kicad_pcb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]
2022-06-17 Working Board, tested over debug serial in DEVMODE
    [BatteryMonitorATTiny3224.sch]
2022-06-23 Eliminated current Amp, using only Attiny3224 ADC
    [BatteryMonitorATTiny3224.kicad_pcb, BatteryMonitorATTiny3224.sch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]
2022-06-25 Working over RS485 after blowing 1 chip and some timing issues
    [batterymon.cfg]
2022-06-26 Fixed and tested over modbus
    [batterymon.py, commandline.h, holdingregisters.h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]
2022-07-15 Added restart and diagnostics
    [batterymon.cfg]
